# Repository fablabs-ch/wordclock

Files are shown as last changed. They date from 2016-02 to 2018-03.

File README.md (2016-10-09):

# WordClock

This is our adaptation of the [Javelin's Word Clock][javelin-word-clock].

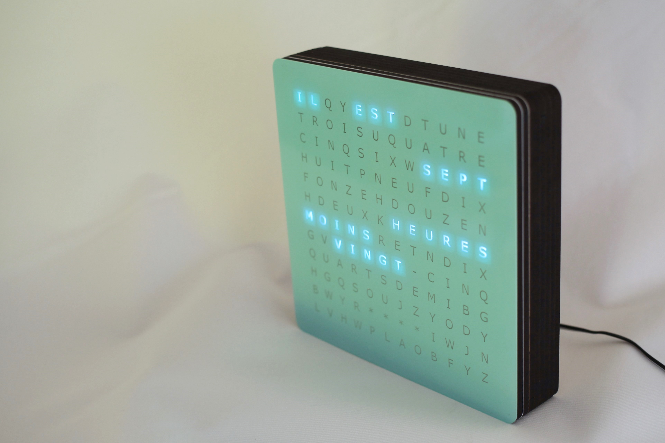
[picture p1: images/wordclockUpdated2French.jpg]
Swiss FabLabs WordClock


## Documentation

You can find all the documentation in the [Wiki][wiki]

* [User manual][user-manual]

## Initial development

The initial development take place on different platforms:

- [Trello][trello-fablabs-ch] for the tasks and progression management.
- [Slack's `#fab-jam_make-athon` channel][slack-fab-jam] for discussions.

## License

This work is licensed under a
[Creative Commons Attribution-NonCommercial-ShareAlike 4.0 International License][by-nc-sa].
Some files may be released under a different license. When this is the case the
license is specified in the file header. This is mainly used for software codes
for which Creative Commons licenses are not well suited.

[][by-nc-sa]

[javelin-word-clock]: http://www.instructables.com/id/Javelins-Word-Clock/
[wiki]: https://github.com/fablabs-ch/wordclock/wiki
[user-manual]: https://github.com/fablabs-ch/wordclock/wiki/User-manual
[trello-fablabs-ch]: https://trello.com/fablabsuisses
[slack-fab-jam]: https://fablabs-ch.slack.com/messages/fab-jam_make-athon/details/
[by-nc-sa]: http://creativecommons.org/licenses/by-nc-sa/4.0/

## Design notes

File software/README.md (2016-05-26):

#Arduino code for the wordclock

#Requirement

The arduino programme require two libraries
 * [TimerOne](https://github.com/PaulStoffregen/TimerOne.git)
 * [DS3231.h](https://github.com/jarzebski/Arduino-DS3231.git)

Clone these librairie in the folder arduino/libraries, restart your arduino IDE and you're good to go. The arduino folder is usually located in _My Documents_ (example : `C:\Users\Gaetan\Documents\Arduino\libraries`)

```sh
cd C:\Users\Gaetan\Documents\Arduino\libraries
git clone https://github.com/PaulStoffregen/TimerOne.git
git clone https://github.com/jarzebski/Arduino-DS3231.git
```

##State diagram
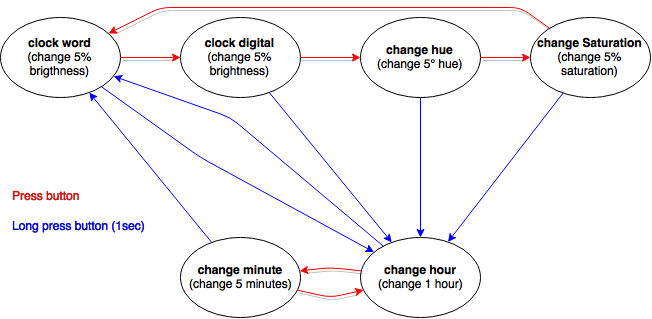
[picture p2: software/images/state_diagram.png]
class diagram State diagram


##Class diagram
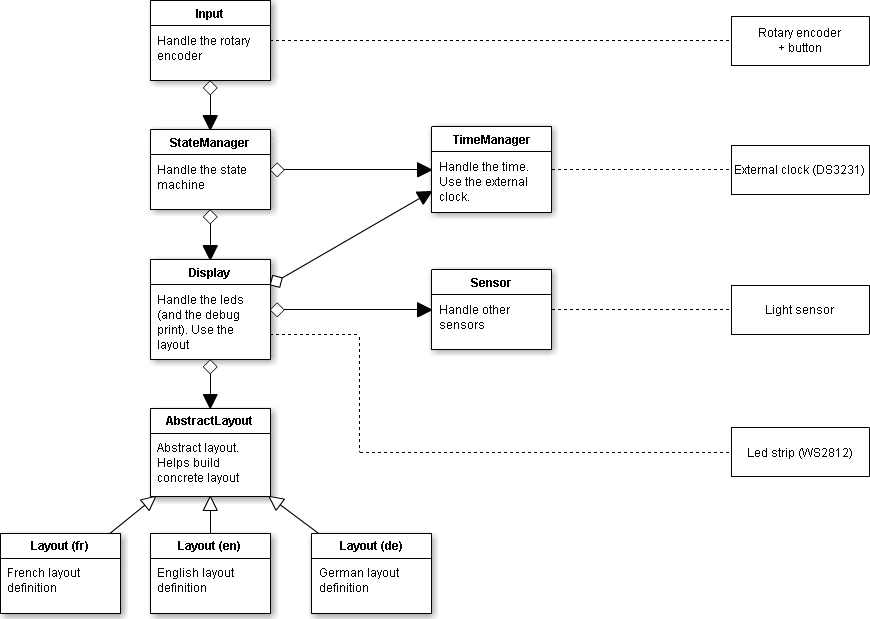
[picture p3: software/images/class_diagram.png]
class diagram Class diagram


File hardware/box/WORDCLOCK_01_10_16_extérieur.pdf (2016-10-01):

découpe
découpe
gravage

Wordclock_Swiss FabLab_extérieur_épaisseur fine

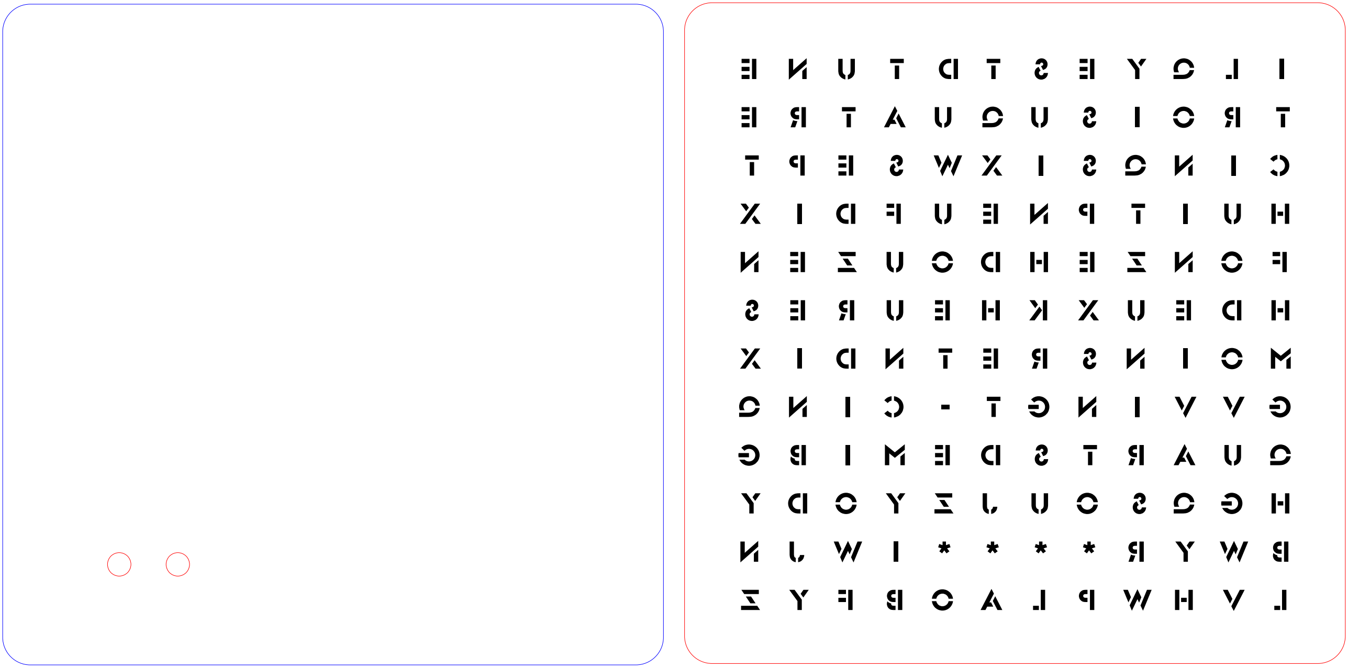
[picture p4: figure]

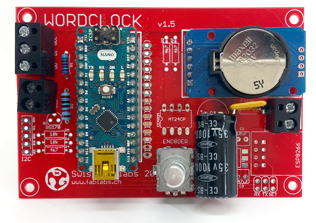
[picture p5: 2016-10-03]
hardware/electronic/pics/default_pcb.jpg

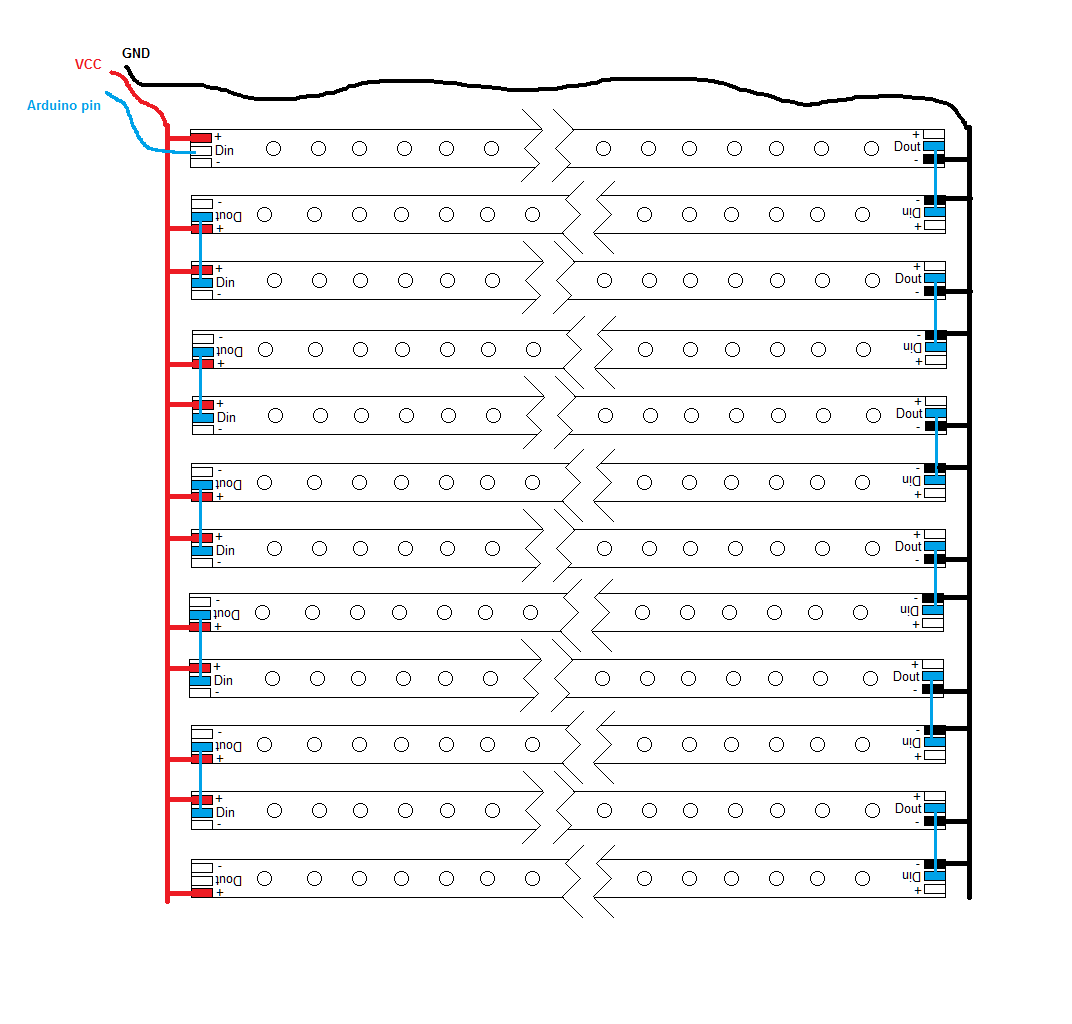
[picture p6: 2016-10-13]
hardware/electronic/pics/led_wordc.bmp

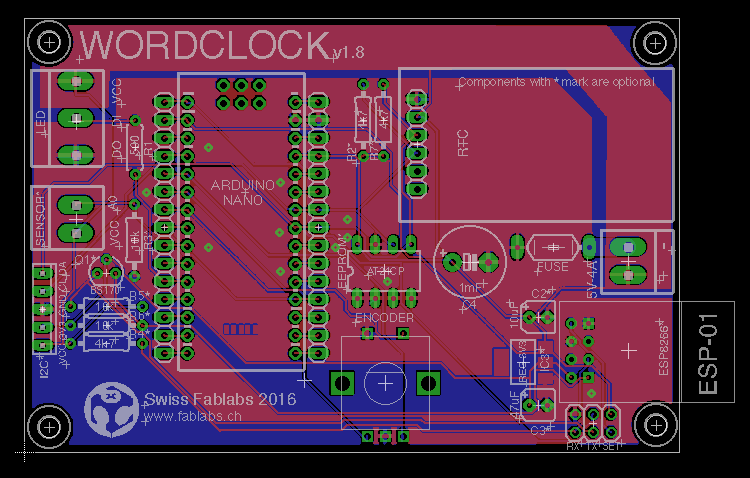
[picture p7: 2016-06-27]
hardware/electronic/pcb_overview.png

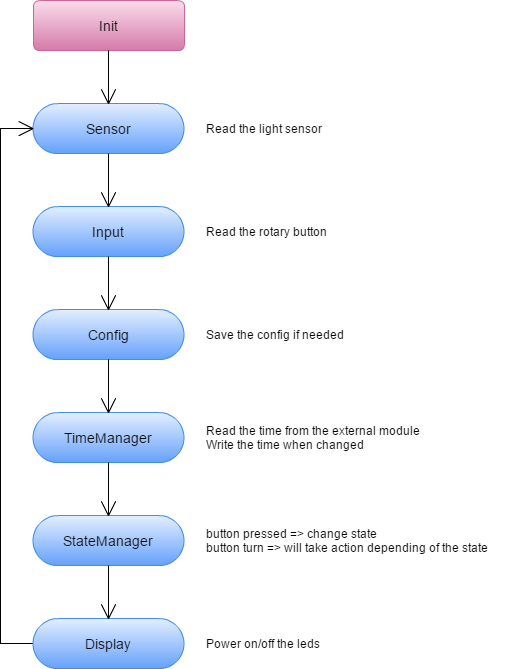
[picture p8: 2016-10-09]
software/images/main_loop.png

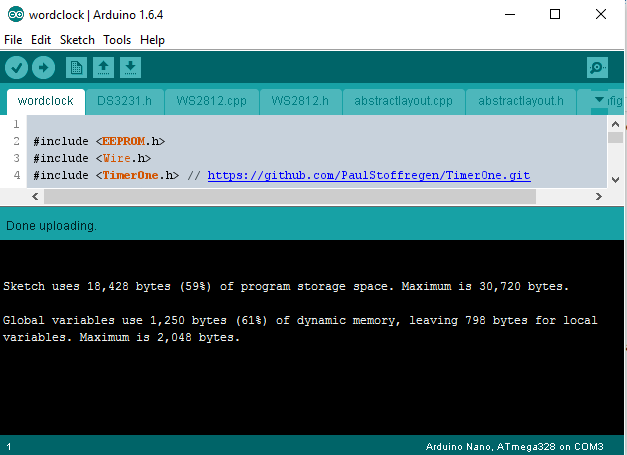
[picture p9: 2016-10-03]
images/wiki/arduino_ide_upload_code.png

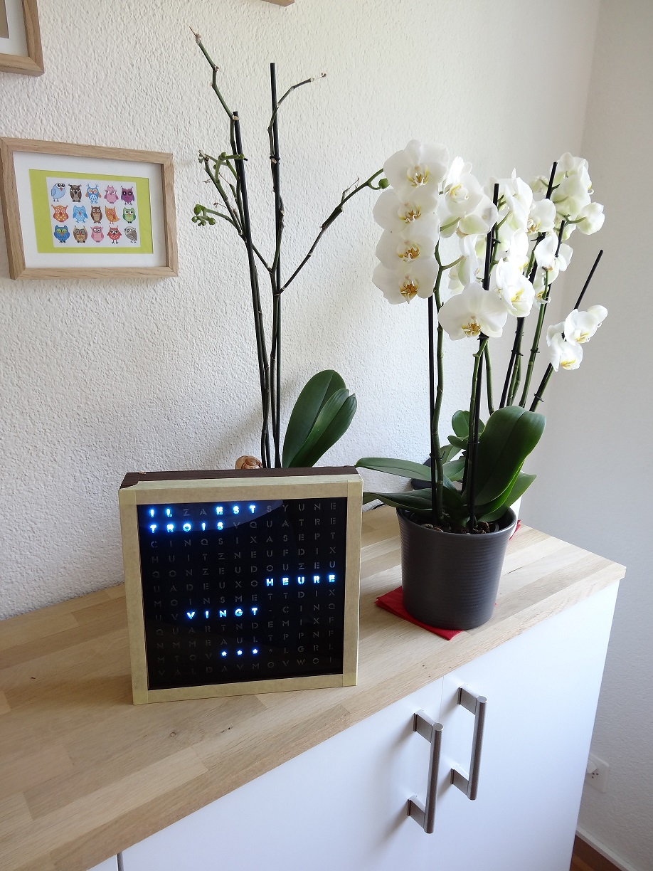
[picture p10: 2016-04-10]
images/wordclock_french.jpg

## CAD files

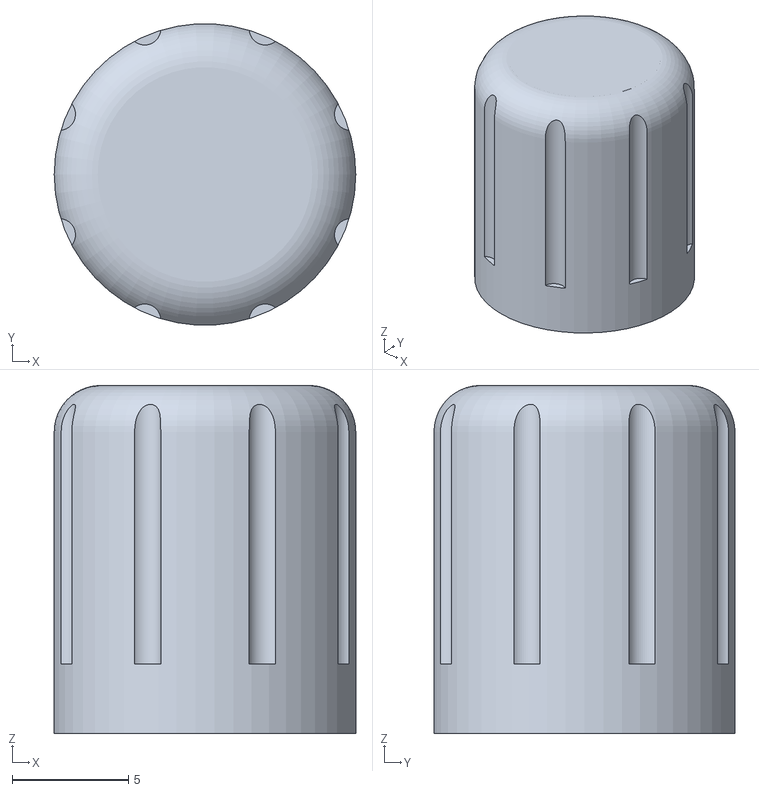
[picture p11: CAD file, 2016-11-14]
hardware/knob/knob.stl
13.0 x 13.0 x 15.0

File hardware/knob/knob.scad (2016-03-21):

/* [Global] */
//Diametre du bouton
Knob_Diameter=13; //[10:30]
//Hauteur du bouton
Knob_Height=15;//[10:20]
//Longueur de l'axe
Axis_Length=10;//[5:15]
//Arrondis
Rounded=2;//[1:3]
//Ajustement
Adjustment=0.5;//[0,0.1,0.2,0.3]
/* [Hidden] */
$fn=50;

difference() {
  union() {
      cylinder(r=Knob_Diameter/2,h=Knob_Height-Rounded);
      translate([0,0,Knob_Height-Rounded]) cylinder(r=Knob_Diameter/2-Rounded,h=Rounded);
      translate([0,0,Knob_Height-Rounded]) rotate_extrude(convexity = 10) translate([Knob_Diameter/2-Rounded,0,0])  circle(r=Rounded);
  }
  
  //translate([0,0,Knob_Height]) rotate([-90,0,0]) cylinder(r=0.5,h=Knob_Diameter/2);
  //translate([0,0,Knob_Height]) sphere(r=0.5);
  
  for (i=[22.5:45:360]) translate([(Knob_Diameter+0.6)*sin(i)/2,(Knob_Diameter+0.6)*cos(i)/2,3]) cylinder(r=0.7,h=Knob_Height);
  difference() {
      translate([0,0,2]) cylinder(r=3.1+Adjustment,h=Axis_Length-2);
      translate([-5,-6.6-Adjustment,2]) cube([10,5,Axis_Length-2]);
  }
  difference() {
      cylinder(r=3+Adjustment,h=2);
      translate([-5,-6.5-Adjustment,0]) cube([10,5,Axis_Length-2]);
  }
}

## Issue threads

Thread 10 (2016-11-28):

Fix main PCB label

gaetancollaud, 2016-11-28:
* DO => GND
* add RTC

ccachin, 2017-05-05:
Done in version 1.9

Closed 2017-05-05.

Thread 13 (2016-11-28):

Add holes on leds plate

ccachin, 2016-11-28:
Actually holes are only present on right and left side.
Adding holes in the middle can avoid using tape to fix led strip

Closed 2016-11-28.

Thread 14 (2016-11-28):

Create a basic pcb

ccachin, 2016-11-28:
A polyvalent PCB seems to be not so attractive and people are a bit lost when they have to find where to solder the components.
Idea is to have a smaller pcb with the only mandatory components.

Can maybe linked with issue #7 Try to use an ESP8266 as brain

Closed 2016-11-28.

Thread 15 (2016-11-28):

Add holes on leds plate

ccachin, 2016-11-28:
Currently holes are only present on right and left side.
Adding holes in the middle can avoid using tape to fix led strip

ccachin, 2018-03-20:
Solved with alternative frame
wordclock/hardware/box/Alternative Frame & pcb ledtstrip/wordclock_frame_strip_placement.svg

Closed 2018-03-20.

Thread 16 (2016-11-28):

Create a basic PCB

ccachin, 2016-11-28:
A polyvalent PCB seems to be not so attractive and people are a bit lost when they have to find where to solder the components.
Idea is to have a smaller pcb with the only mandatory components.

Can maybe linked with issue #7 Try to use an ESP8266 as brain

gaetancollaud, 2016-12-17:
I tried PlatformIO recently. It's amazing how the ESP8266 is easy with this platform. Of course we have a lot of refactoring to do... :(

ccachin, 2016-12-19:
What kind of refactoring should we do to use PlateformIO?

gaetancollaud, 2016-12-19:
Since I used C++ 90% of the code is compatible. The issue will be the led strip and the i2c communication. We have to use other libraries.

ccachin, 2017-05-05:
Basic pcb created. See wordclock_zero

Closed 2017-05-05.

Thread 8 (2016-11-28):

Create a PCB to hold the rotary button

gaetancollaud, 2016-11-28:

ccachin, 2017-05-05:
Finally decided to reject this issue. Pull-up are worst on rotary encoder module.

Closed 2017-05-05.

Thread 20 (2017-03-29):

Wire RX/TX

ccachin, 2017-03-29:
Replace RX/TX jumpers with wires

ccachin, 2017-05-05:
Done in version 1.9

Closed 2017-05-05.

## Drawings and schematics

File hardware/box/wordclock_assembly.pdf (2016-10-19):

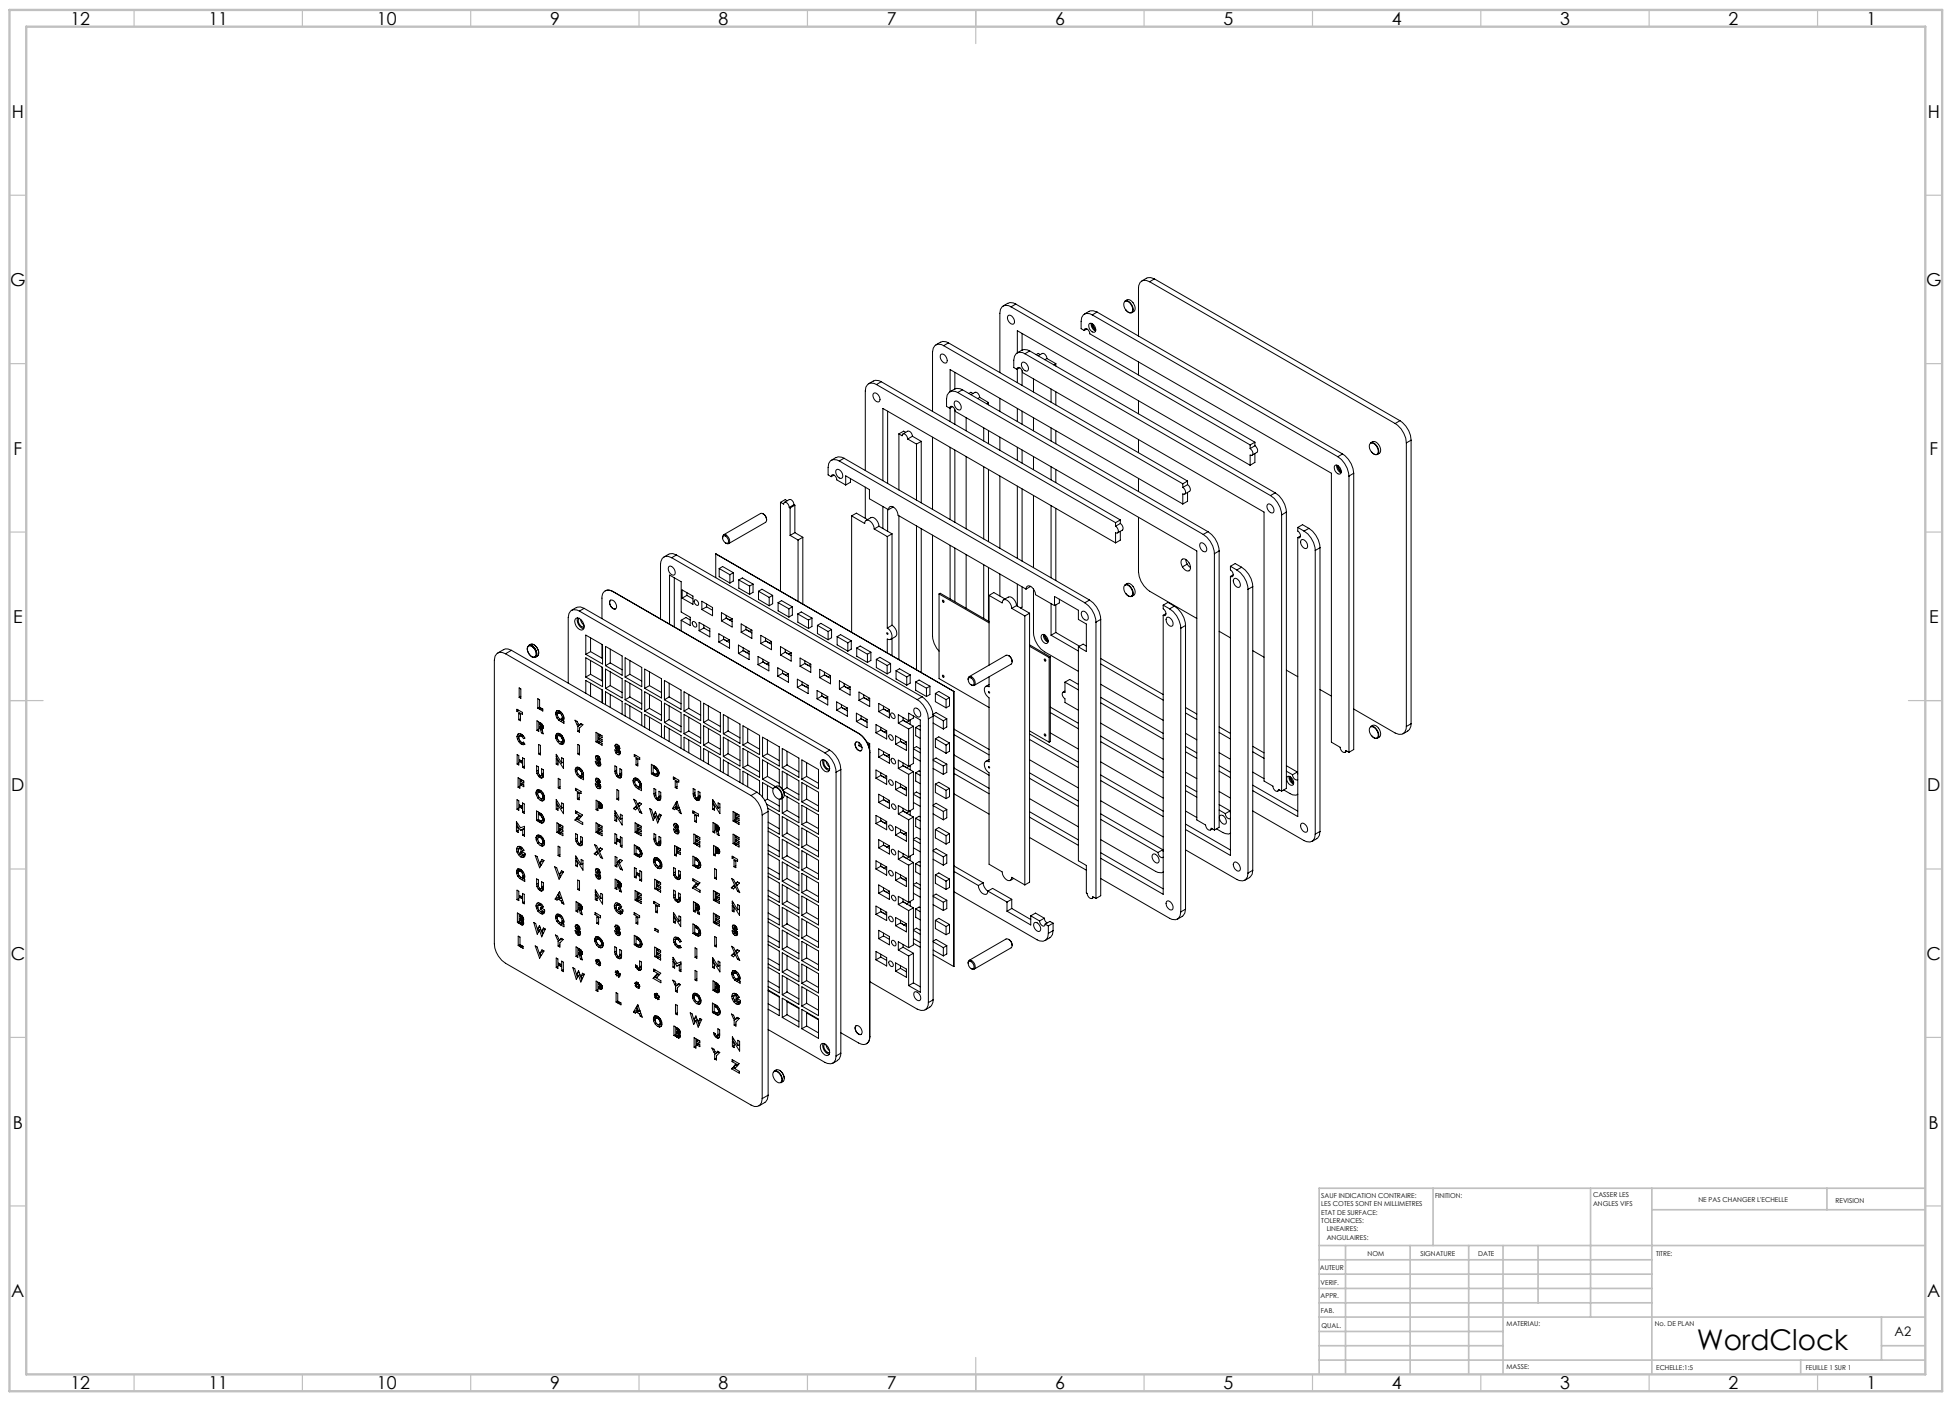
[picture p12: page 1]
ECHELLE:1:5; FEUILLE 1 SUR 1

SAUF INDICATION CONTRAIRE: LES COTES SONT EN MILLIMETRES ETAT DE SURFACE: TOLERANCES: LINEAIRES: ANGULAIRES: | FINITION: | CASSER LES ANGLES VIFS | NE PAS CHANGER L'ECHELLE | REVISION

NOM | SIGNATURE | DATE | | | | TITRE:

AUTEUR
VERIF.
APPR.
FAB.
QUAL. | | | | MATERIAU: | No. DE PLAN WordClock | A2

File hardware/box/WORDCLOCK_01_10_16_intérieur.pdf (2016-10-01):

2x

2x

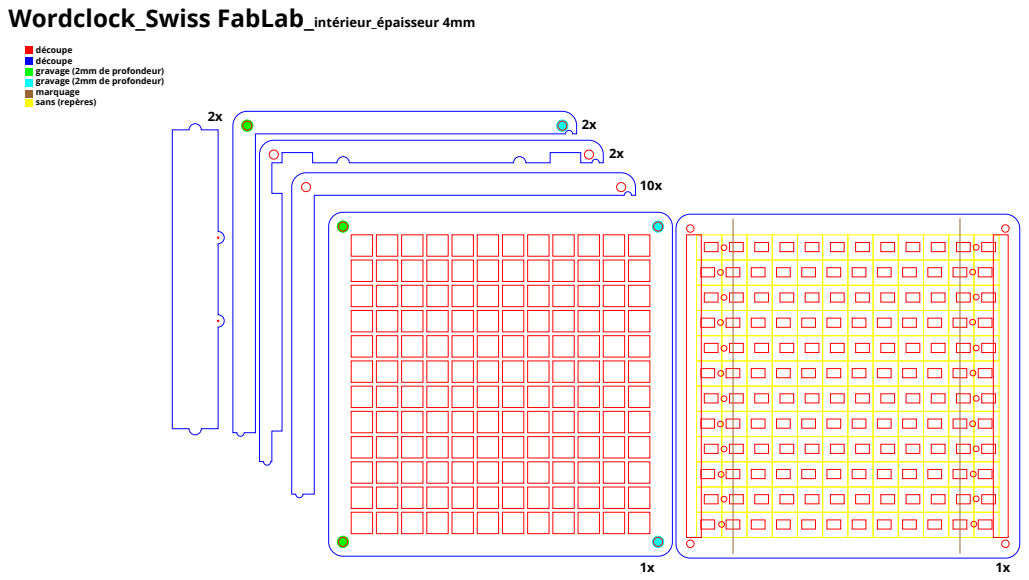
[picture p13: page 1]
Wordclock_Swiss FabLab_intérieur_épaisseur 4mm

découpe
gravage (2mm de profondeur)
marquage
sans (repères)

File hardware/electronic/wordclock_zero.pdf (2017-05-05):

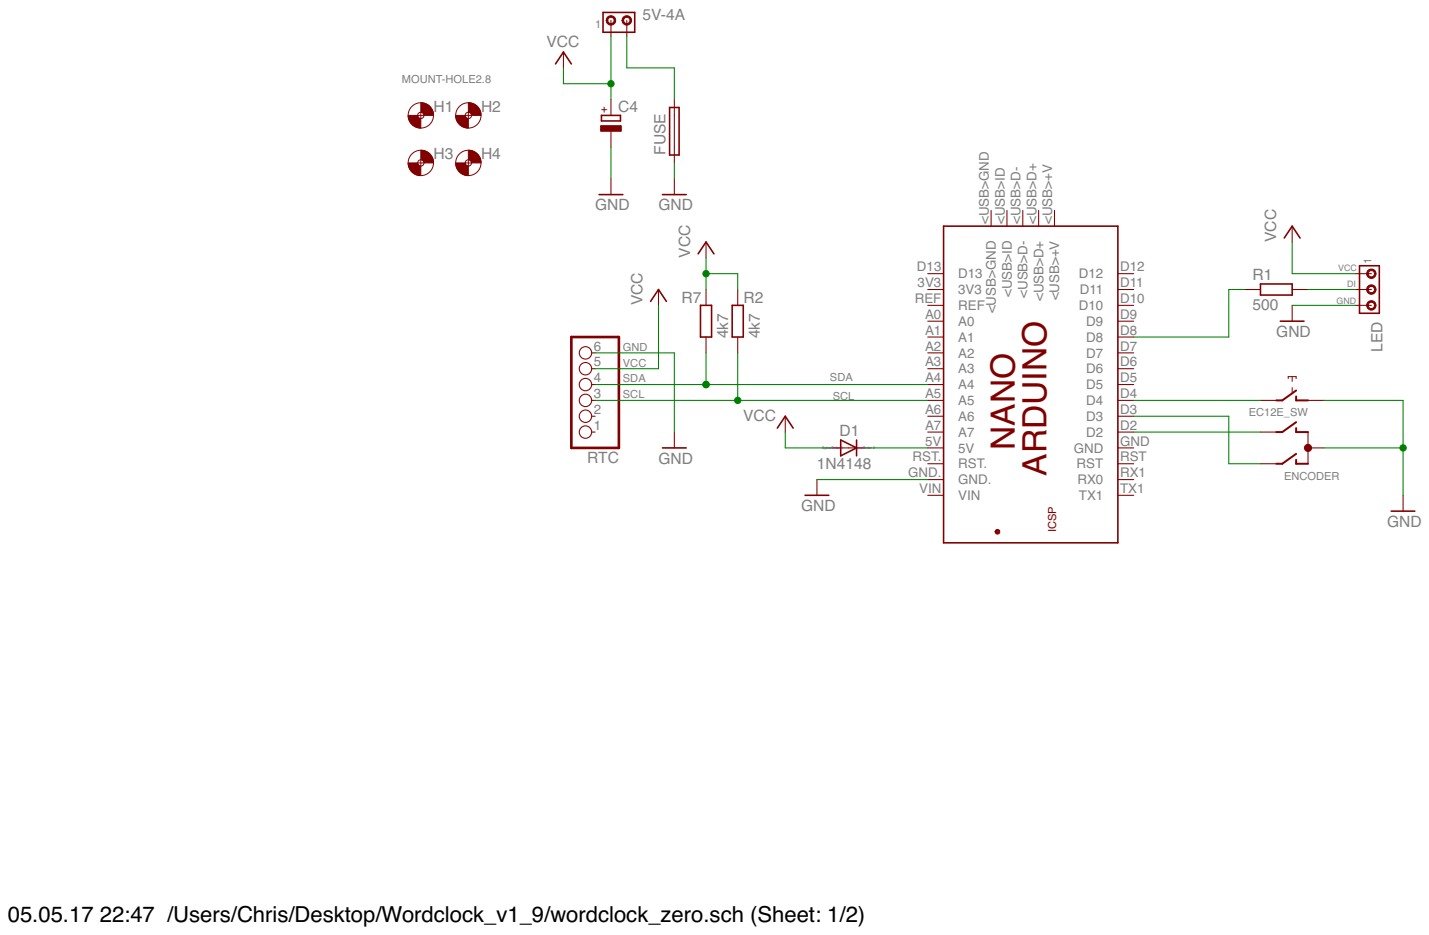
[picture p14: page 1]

05.05.17 22:47 /Users/Chris/Desktop/Wordclock_v1_9/wordclock_zero.sch (Sheet: 1/2)

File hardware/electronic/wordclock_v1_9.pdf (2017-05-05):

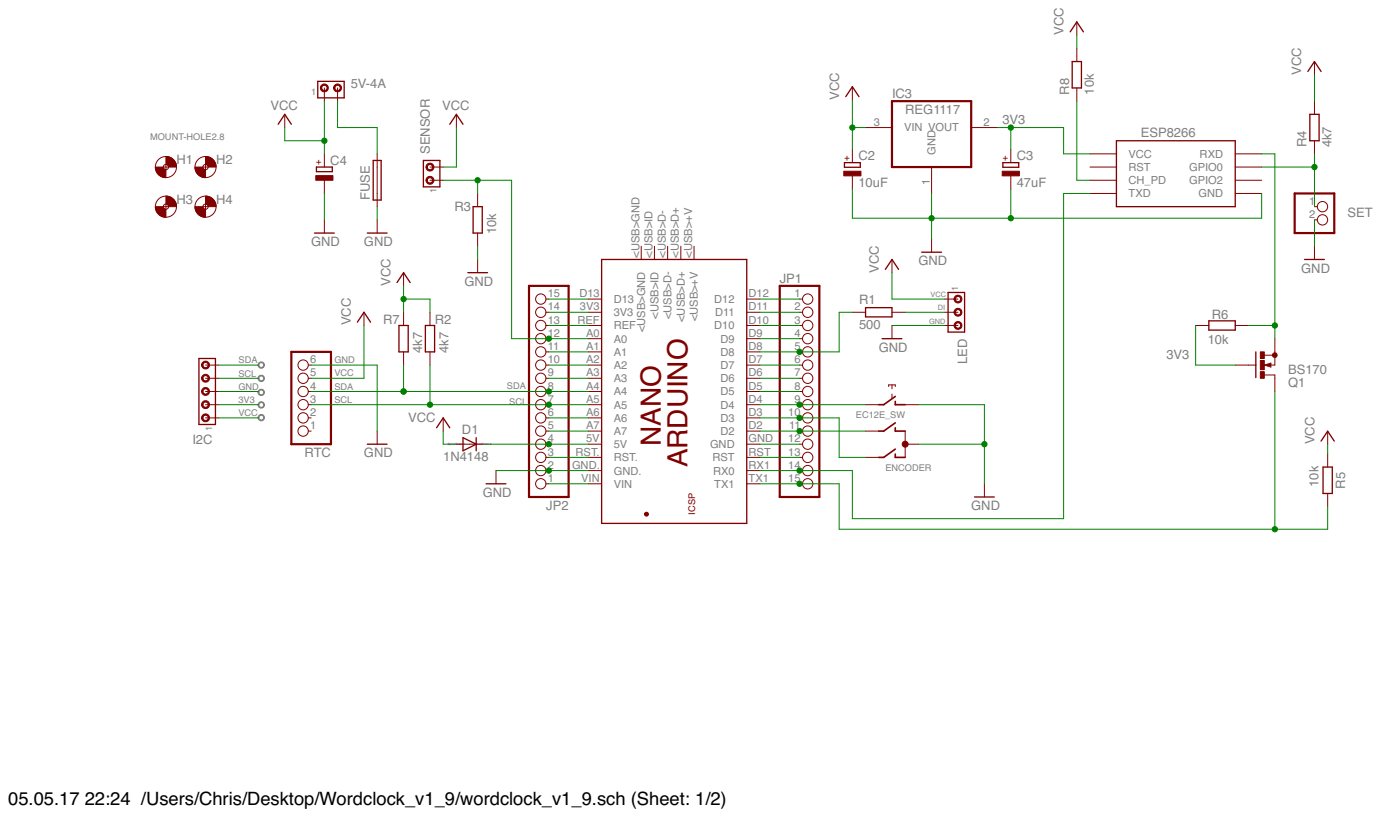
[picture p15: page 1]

05.05.17 22:24 /Users/Chris/Desktop/Wordclock_v1_9/wordclock_v1_9.sch (Sheet: 1/2)

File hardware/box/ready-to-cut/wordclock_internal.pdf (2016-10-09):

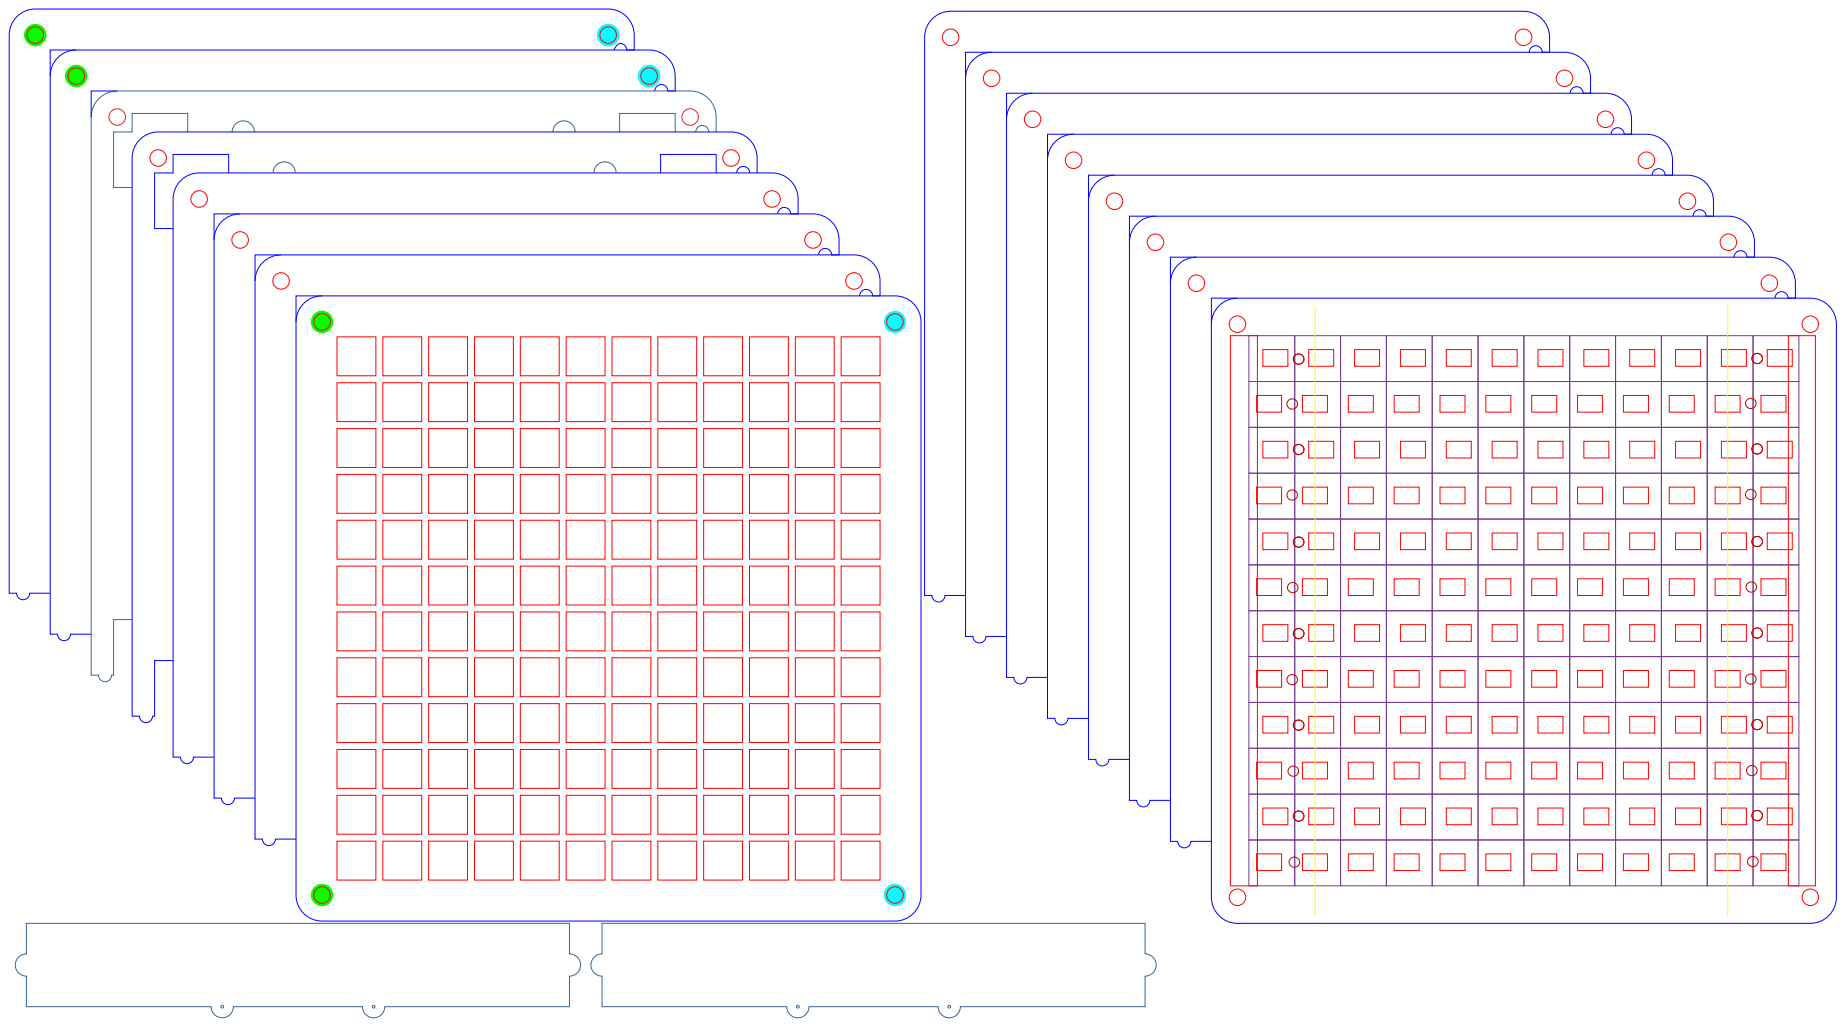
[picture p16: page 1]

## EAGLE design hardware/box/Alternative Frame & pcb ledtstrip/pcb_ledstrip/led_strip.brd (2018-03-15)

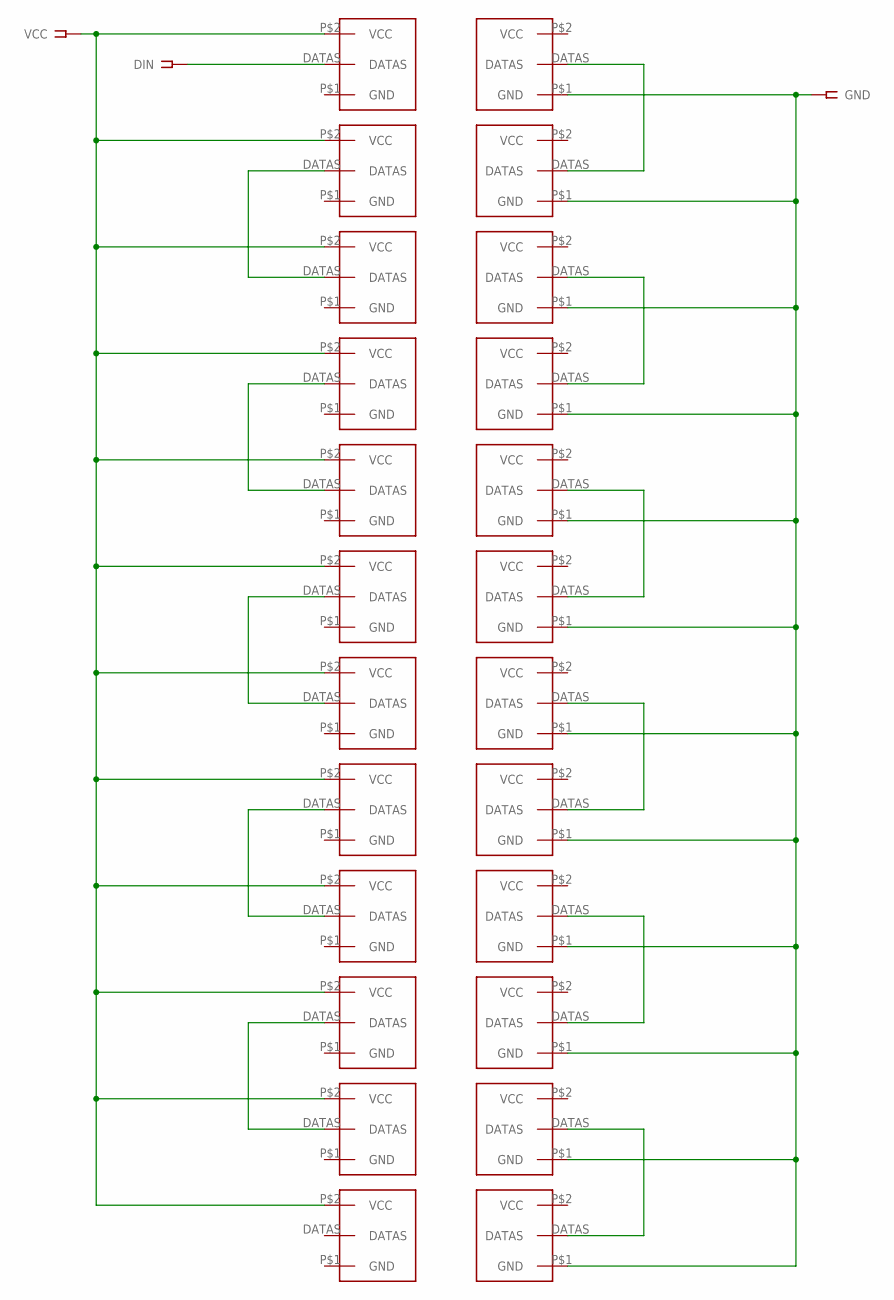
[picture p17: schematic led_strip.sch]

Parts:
1: 1; LED_STRIP
2, 3, 4, 5, 6, 7, 8, 9, 10, 11, 12, 13, 14, 15, 16, 17, 18, 19, 20, 21, 22, 23, 24: LED_STRIP
DIN: DATA; SSW-101-02-S-S
GND: GND; SSW-101-02-S-S
VCC: VCC; SSW-101-02-S-S

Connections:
GND: 1.P$1 (GND), 2.P$1 (GND), 3.P$1 (GND), 4.P$1 (GND), 5.P$1 (GND), 6.P$1 (GND), 7.P$1 (GND), 8.P$1 (GND), 9.P$1 (GND), 10.P$1 (GND), 11.P$1 (GND), 12.P$1 (GND), GND.1
unnamed: 13.DATAS, DIN.1
unnamed: 1.DATAS, 2.DATAS
unnamed: 14.DATAS, 15.DATAS
unnamed: 3.DATAS, 4.DATAS
unnamed: 16.DATAS, 17.DATAS
unnamed: 5.DATAS, 6.DATAS
unnamed: 18.DATAS, 19.DATAS
unnamed: 7.DATAS, 8.DATAS
unnamed: 20.DATAS, 21.DATAS
unnamed: 22.DATAS, 23.DATAS
unnamed: 9.DATAS, 10.DATAS
unnamed: 11.DATAS, 12.DATAS
VCC: 13.P$2 (VCC), 14.P$2 (VCC), 15.P$2 (VCC), 16.P$2 (VCC), 17.P$2 (VCC), 18.P$2 (VCC), 19.P$2 (VCC), 20.P$2 (VCC), 21.P$2 (VCC), 22.P$2 (VCC), 23.P$2 (VCC), 24.P$2 (VCC), VCC.1

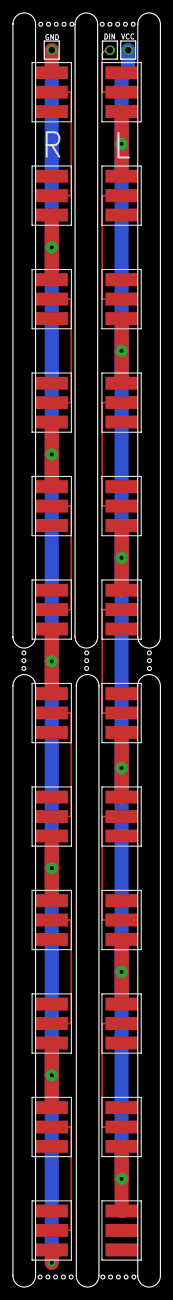
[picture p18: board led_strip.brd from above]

Board: 2 copper layers, 22.8 x 197.0 mm, 27 parts (0 on the bottom side), 14 nets.

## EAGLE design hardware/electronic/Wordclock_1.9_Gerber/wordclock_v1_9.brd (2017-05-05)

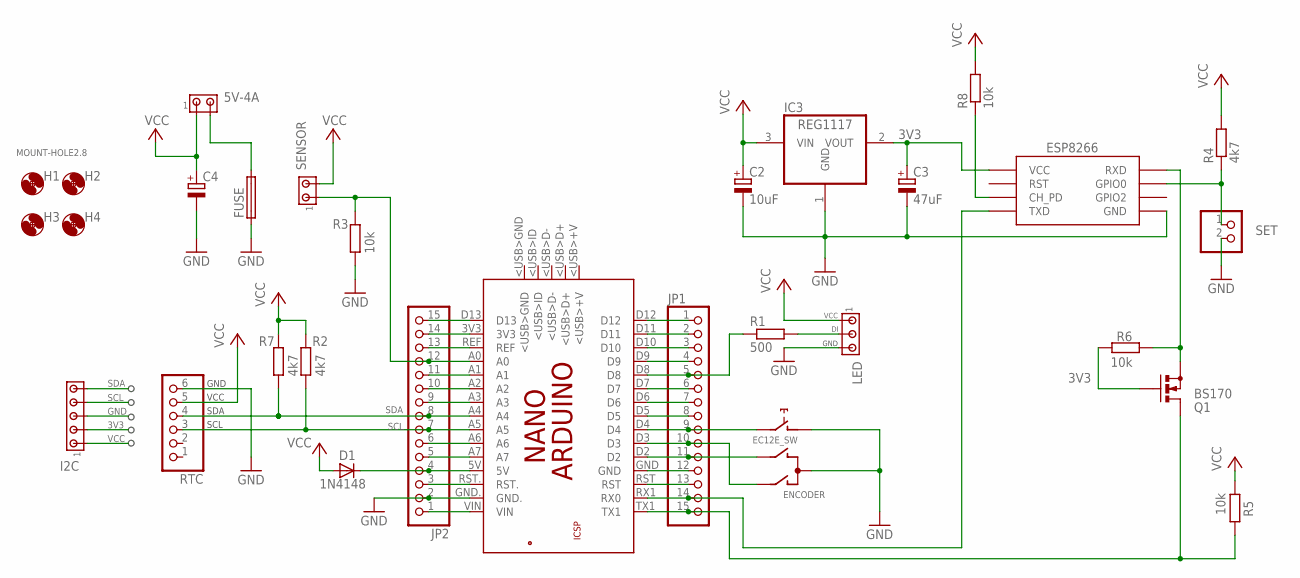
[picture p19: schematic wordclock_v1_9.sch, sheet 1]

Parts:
5V-4A: 5V-4A; 1X2MTA
C2: 10uF; B45181A
C3: 47uF; B45181A
C4: CPOL-EUE5-10.5; E5-10,5
D1: 1N4148; DO35-10
ENCODER: EC12E_SW; ALPS_EC12E_SW
ESP8266: ESP01
FUSE: FUSELITTLEFUSE; LITTLEFUSE
H1, H2, H3, H4: MOUNT-HOLE2.8; 2,8
I2C: MTA05-100; 10X05MTA
IC3: REG1117; SOT223
JP1, JP2: PINHD-1X15; 1X15
LED: MTA03-156; 1X3MTA
PCB2: ARDUINO_NANO
Q1: BS170; SOT54E
R1: 500; 0207/7
R2, R4, R7: 4k7; 0207/10
R3, R5, R6, R8: 10k; 0207/10
RTC: PINHD-1X6; 1X06
SENSOR: MTA02-156; 1X2MTA
SET: PINHD-1X2; 1X02

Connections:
3V3: C3.+, ESP8266.VCC, I2C.2, IC3.2 (VOUT), Q1.G, R6.1
DI: LED.2, R1.2
GND: C2.-, C3.-, C4.-, ENCODER.C, ENCODER.D (1), ESP8266.GND, FUSE.1, I2C.3, IC3.1 (GND), JP2.2, LED.3, PCB2.GND., R3.1, RTC.6, SET.2
unnamed: ESP8266.CH_PD, R8.1
unnamed: JP1.1, PCB2.D12
unnamed: JP1.2, PCB2.D11
unnamed: JP1.5, PCB2.D8, R1.1
unnamed: 5V-4A.2, FUSE.2
unnamed: ENCODER.B, JP1.11, PCB2.D2
unnamed: ENCODER.A, JP1.10, PCB2.D3
unnamed: ENCODER.E (2), JP1.9, PCB2.D4
unnamed: JP1.3, PCB2.D10
unnamed: JP1.15, PCB2.TX1, Q1.D, R5.2
unnamed: D1.C, JP2.4, PCB2.5V
unnamed: JP2.12, PCB2.A0, R3.2, SENSOR.1
unnamed: JP1.4, PCB2.D9
unnamed: JP1.6, PCB2.D7
unnamed: ESP8266.RX (RXD), Q1.S, R6.2
unnamed: JP1.7, PCB2.D6
unnamed: JP1.8, PCB2.D5
unnamed: JP1.12, PCB2.GND
unnamed: JP1.13, PCB2.RST
unnamed: JP2.15, PCB2.D13
unnamed: JP2.14, PCB2.3V3
unnamed: JP2.13, PCB2.REF
unnamed: JP2.11, PCB2.A1
unnamed: JP2.10, PCB2.A2
unnamed: JP2.9, PCB2.A3
unnamed: JP2.6, PCB2.A6
unnamed: JP2.5, PCB2.A7
unnamed: JP2.3, PCB2.RST.
unnamed: JP2.1, PCB2.VIN
RX: ESP8266.TX (TXD), JP1.14, PCB2.RX1 (RX0)
SCL: I2C.4, JP2.7, PCB2.A5, R2.1, RTC.3
SDA: I2C.5, JP2.8, PCB2.A4, R7.1, RTC.4
SET: ESP8266.GPIO0, R4.1, SET.1
VCC: 5V-4A.1, C2.+, C4.+, D1.A, I2C.1, IC3.3 (VIN), LED.1, R2.2, R4.2, R5.1, R7.2, R8.2, RTC.5, SENSOR.2

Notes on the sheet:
SDA
SCL
GND
VCC

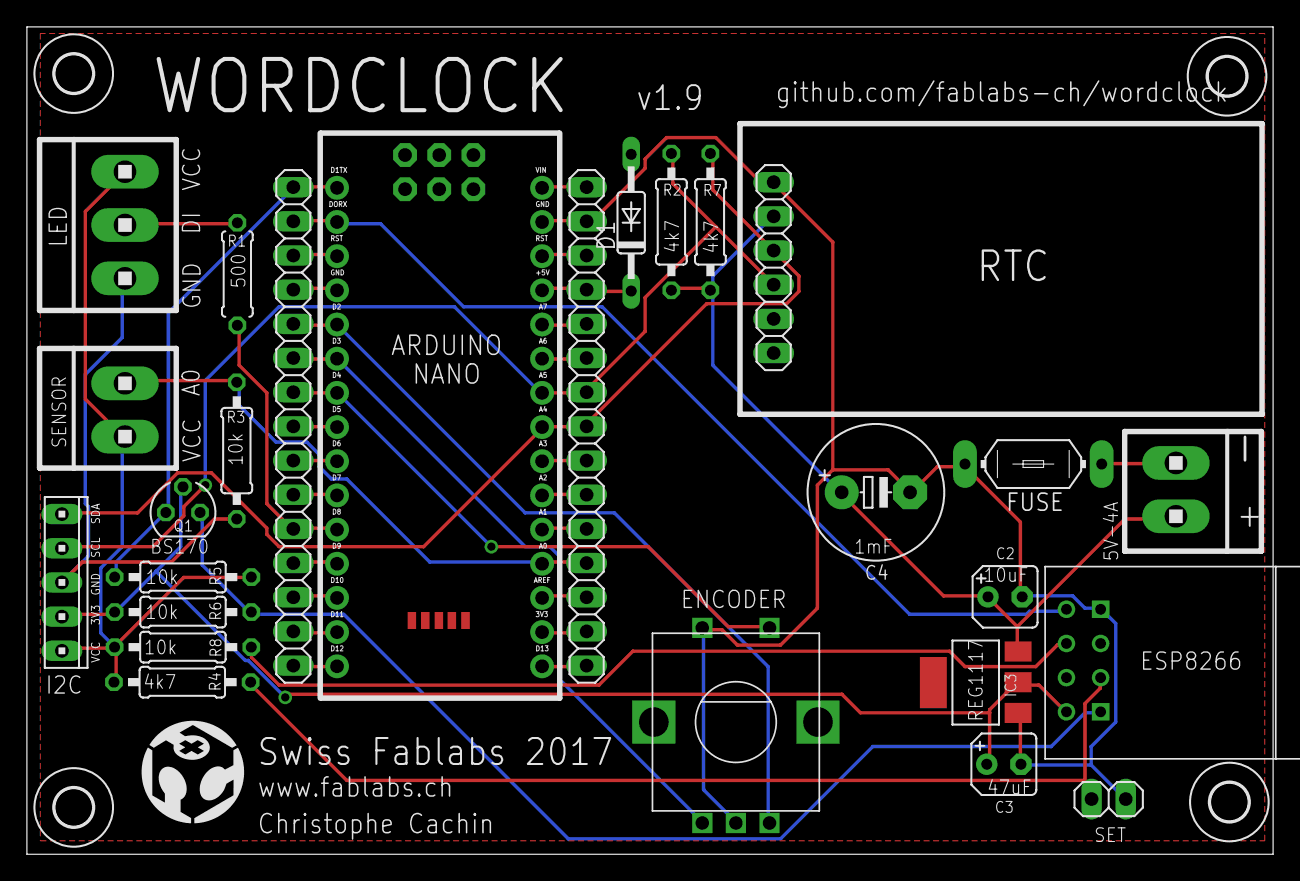
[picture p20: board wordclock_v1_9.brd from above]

Board: 2 copper layers, 92.6 x 61.5 mm, 30 parts (0 on the bottom side), 37 nets.

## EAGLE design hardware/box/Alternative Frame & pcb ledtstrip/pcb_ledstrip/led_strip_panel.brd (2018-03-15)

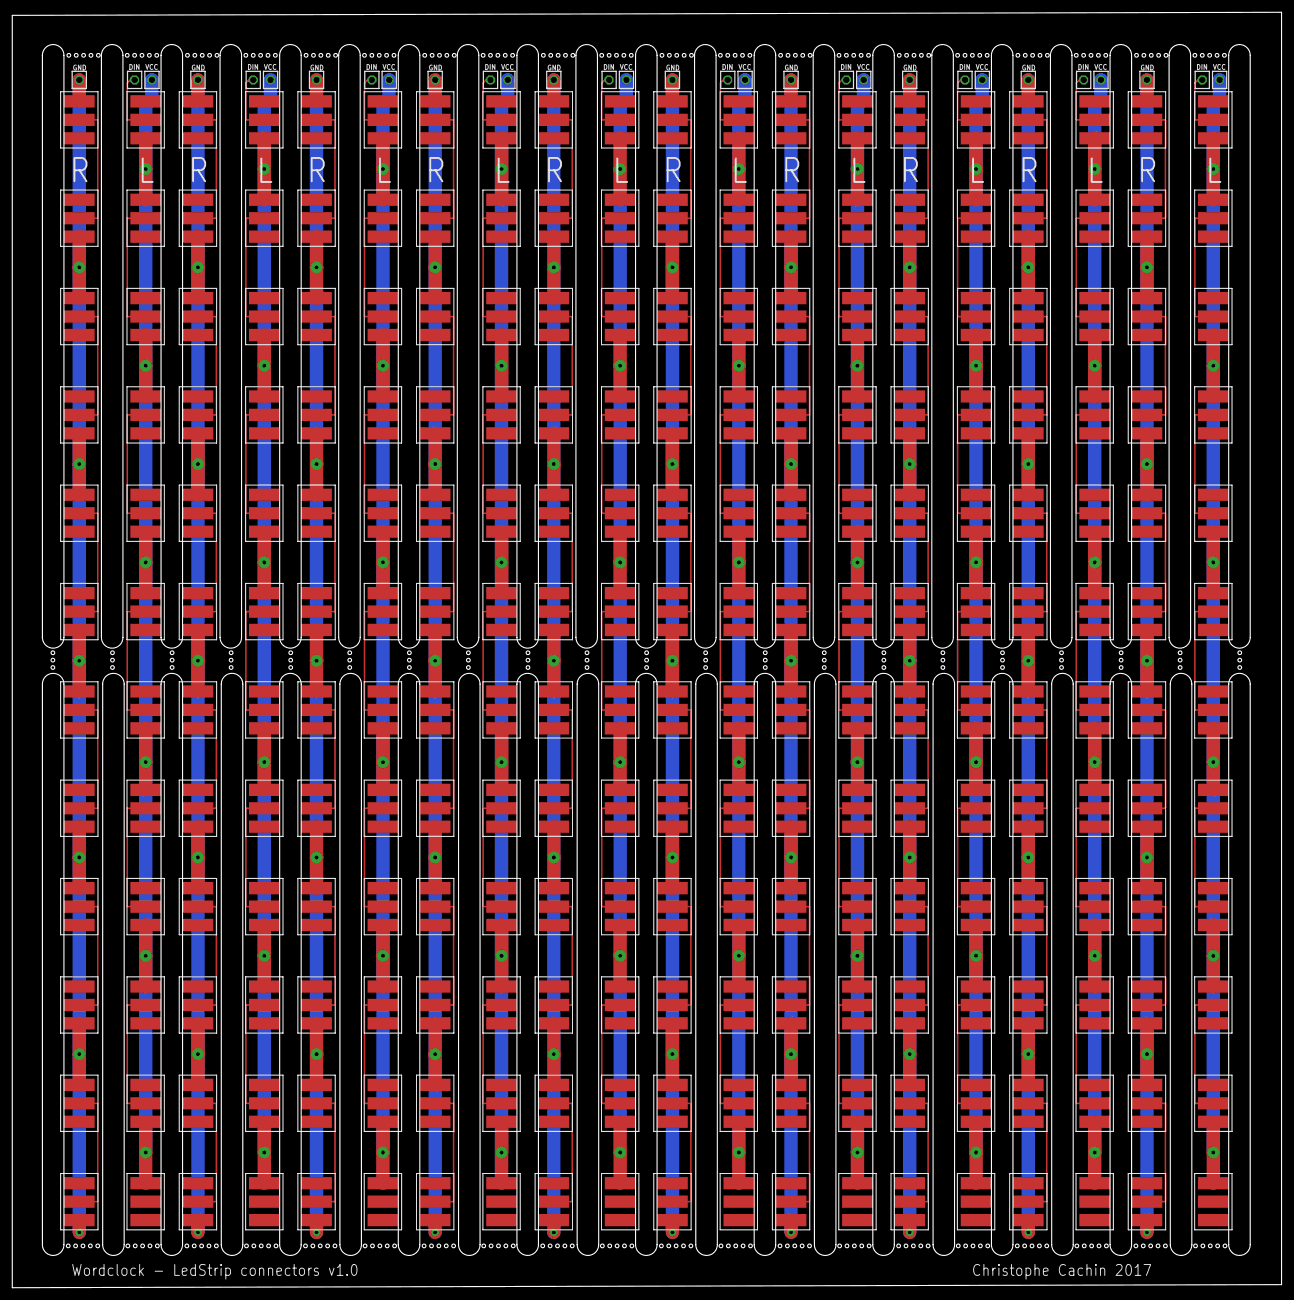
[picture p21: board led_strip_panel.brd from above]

Board: 2 copper layers, 206.5 x 207.5 mm, 270 parts (0 on the bottom side), 140 nets.

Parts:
1, 25, 49, 73, 97, 121, 145, 169, 193, 217: 1; LED_STRIP
2, 3, 4, 5, 6, 7, 8, 9, 10, 11, 12, 13, 14, 15, 16, 17, 18, 19, 20, 21, 22, 23, 24, 26, 27, 28, 29, 30, 31, 32, 33, 34, 35, 36, 37, 38, 39, 40, 41, 42, 43, 44, 45, 46, 47, 48, 50, 51, 52, 53, 54, 55, 56, 57, 58, 59, 60, 61, 62, 63, 64, 65, 66, 67, 68, 69, 70, 71, 72, 74, 75, 76, 77, 78, 79, 80, 81, 82, 83, 84, 85, 86, 87, 88, 89, 90, 91, 92, 93, 94, 95, 96, 98, 99, 100, 101, 102, 103, 104, 105, 106, 107, 108, 109, 110, 111, 112, 113, 114, 115, 116, 117, 118, 119, 120, 122, 123, 124, 125, 126, 127, 128, 129, 130, 131, 132, 133, 134, 135, 136, 137, 138, 139, 140, 141, 142, 143, 144, 146, 147, 148, 149, 150, 151, 152, 153, 154, 155, 156, 157, 158, 159, 160, 161, 162, 163, 164, 165, 166, 167, 168, 170, 171, 172, 173, 174, 175, 176, 177, 178, 179, 180, 181, 182, 183, 184, 185, 186, 187, 188, 189, 190, 191, 192, 194, 195, 196, 197, 198, 199, 200, 201, 202, 203, 204, 205, 206, 207, 208, 209, 210, 211, 212, 213, 214, 215, 216, 218, 219, 220, 221, 222, 223, 224, 225, 226, 227, 228, 229, 230, 231, 232, 233, 234, 235, 236, 237, 238, 239, 240: LED_STRIP
DIN, DIN1, DIN2, DIN3, DIN4, DIN5, DIN6, DIN7, DIN8, DIN9: DATA; SSW-101-02-S-S
GND, GND1, GND2, GND3, GND4, GND5, GND6, GND7, GND8, GND9: GND; SSW-101-02-S-S
VCC, VCC1, VCC2, VCC3, VCC4, VCC5, VCC6, VCC7, VCC8, VCC9: VCC; SSW-101-02-S-S

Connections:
GND: 1.P$1, 2.P$1, 3.P$1, 4.P$1, 5.P$1, 6.P$1, 7.P$1, 8.P$1, 9.P$1, 10.P$1, 11.P$1, 12.P$1, GND.1
GND1: 25.P$1, 26.P$1, 27.P$1, 28.P$1, 36.P$1, 42.P$1, 43.P$1, 44.P$1, 45.P$1, 46.P$1, 47.P$1, 48.P$1, GND1.1
GND2: 49.P$1, 50.P$1, 51.P$1, 52.P$1, 60.P$1, 66.P$1, 67.P$1, 68.P$1, 69.P$1, 70.P$1, 71.P$1, 72.P$1, GND2.1
GND3: 73.P$1, 74.P$1, 75.P$1, 76.P$1, 84.P$1, 90.P$1, 91.P$1, 92.P$1, 93.P$1, 94.P$1, 95.P$1, 96.P$1, GND3.1
GND4: 97.P$1, 98.P$1, 99.P$1, 100.P$1, 108.P$1, 114.P$1, 115.P$1, 116.P$1, 117.P$1, 118.P$1, 119.P$1, 120.P$1, GND4.1
GND5: 121.P$1, 122.P$1, 123.P$1, 124.P$1, 132.P$1, 138.P$1, 139.P$1, 140.P$1, 141.P$1, 142.P$1, 143.P$1, 144.P$1, GND5.1
GND6: 145.P$1, 146.P$1, 147.P$1, 148.P$1, 156.P$1, 162.P$1, 163.P$1, 164.P$1, 165.P$1, 166.P$1, 167.P$1, 168.P$1, GND6.1
GND7: 169.P$1, 170.P$1, 171.P$1, 172.P$1, 180.P$1, 186.P$1, 187.P$1, 188.P$1, 189.P$1, 190.P$1, 191.P$1, 192.P$1, GND7.1
GND8: 193.P$1, 194.P$1, 195.P$1, 196.P$1, 204.P$1, 210.P$1, 211.P$1, 212.P$1, 213.P$1, 214.P$1, 215.P$1, 216.P$1, GND8.1
GND9: 217.P$1, 218.P$1, 219.P$1, 220.P$1, 228.P$1, 234.P$1, 235.P$1, 236.P$1, 237.P$1, 238.P$1, 239.P$1, 240.P$1, GND9.1
unnamed: 13.DATAS, DIN.1
unnamed: 1.DATAS, 2.DATAS
unnamed: 14.DATAS, 15.DATAS
unnamed: 3.DATAS, 4.DATAS
unnamed: 16.DATAS, 17.DATAS
unnamed: 5.DATAS, 6.DATAS
unnamed: 18.DATAS, 19.DATAS
unnamed: 7.DATAS, 8.DATAS
unnamed: 20.DATAS, 21.DATAS
unnamed: 22.DATAS, 23.DATAS
unnamed: 9.DATAS, 10.DATAS
unnamed: 11.DATAS, 12.DATAS
unnamed: 29.DATAS, DIN1.1
unnamed: 25.DATAS, 36.DATAS
unnamed: 30.DATAS, 31.DATAS
unnamed: 42.DATAS, 43.DATAS
unnamed: 32.DATAS, 33.DATAS
unnamed: 44.DATAS, 45.DATAS
unnamed: 34.DATAS, 35.DATAS
unnamed: 46.DATAS, 47.DATAS
unnamed: 37.DATAS, 38.DATAS
unnamed: 39.DATAS, 40.DATAS
unnamed: 26.DATAS, 48.DATAS
unnamed: 27.DATAS, 28.DATAS
unnamed: 53.DATAS, DIN2.1
unnamed: 49.DATAS, 60.DATAS
unnamed: 54.DATAS, 55.DATAS
unnamed: 66.DATAS, 67.DATAS
unnamed: 56.DATAS, 57.DATAS
unnamed: 68.DATAS, 69.DATAS
unnamed: 58.DATAS, 59.DATAS
unnamed: 70.DATAS, 71.DATAS
unnamed: 61.DATAS, 62.DATAS
unnamed: 63.DATAS, 64.DATAS
unnamed: 50.DATAS, 72.DATAS
unnamed: 51.DATAS, 52.DATAS
unnamed: 77.DATAS, DIN3.1
unnamed: 73.DATAS, 84.DATAS
unnamed: 78.DATAS, 79.DATAS
unnamed: 90.DATAS, 91.DATAS
unnamed: 80.DATAS, 81.DATAS
unnamed: 92.DATAS, 93.DATAS
unnamed: 82.DATAS, 83.DATAS
unnamed: 94.DATAS, 95.DATAS
unnamed: 85.DATAS, 86.DATAS
unnamed: 87.DATAS, 88.DATAS
unnamed: 74.DATAS, 96.DATAS
unnamed: 75.DATAS, 76.DATAS
unnamed: 101.DATAS, DIN4.1
unnamed: 97.DATAS, 108.DATAS
unnamed: 102.DATAS, 103.DATAS
unnamed: 114.DATAS, 115.DATAS
unnamed: 104.DATAS, 105.DATAS
unnamed: 116.DATAS, 117.DATAS
unnamed: 106.DATAS, 107.DATAS
unnamed: 118.DATAS, 119.DATAS
unnamed: 109.DATAS, 110.DATAS
unnamed: 111.DATAS, 112.DATAS
unnamed: 98.DATAS, 120.DATAS
unnamed: 99.DATAS, 100.DATAS
unnamed: 125.DATAS, DIN5.1
unnamed: 121.DATAS, 132.DATAS
unnamed: 126.DATAS, 127.DATAS
unnamed: 138.DATAS, 139.DATAS
unnamed: 128.DATAS, 129.DATAS
unnamed: 140.DATAS, 141.DATAS
unnamed: 130.DATAS, 131.DATAS
unnamed: 142.DATAS, 143.DATAS
unnamed: 133.DATAS, 134.DATAS
unnamed: 135.DATAS, 136.DATAS
unnamed: 122.DATAS, 144.DATAS
unnamed: 123.DATAS, 124.DATAS
unnamed: 149.DATAS, DIN6.1
unnamed: 145.DATAS, 156.DATAS
unnamed: 150.DATAS, 151.DATAS
unnamed: 162.DATAS, 163.DATAS
unnamed: 152.DATAS, 153.DATAS
unnamed: 164.DATAS, 165.DATAS
unnamed: 154.DATAS, 155.DATAS
unnamed: 166.DATAS, 167.DATAS
unnamed: 157.DATAS, 158.DATAS
unnamed: 159.DATAS, 160.DATAS
unnamed: 146.DATAS, 168.DATAS
unnamed: 147.DATAS, 148.DATAS
unnamed: 173.DATAS, DIN7.1
unnamed: 169.DATAS, 180.DATAS
unnamed: 174.DATAS, 175.DATAS
unnamed: 186.DATAS, 187.DATAS
unnamed: 176.DATAS, 177.DATAS
unnamed: 188.DATAS, 189.DATAS
unnamed: 178.DATAS, 179.DATAS
unnamed: 190.DATAS, 191.DATAS
unnamed: 181.DATAS, 182.DATAS
unnamed: 183.DATAS, 184.DATAS
unnamed: 170.DATAS, 192.DATAS
unnamed: 171.DATAS, 172.DATAS
unnamed: 197.DATAS, DIN8.1
unnamed: 193.DATAS, 204.DATAS
unnamed: 198.DATAS, 199.DATAS
unnamed: 210.DATAS, 211.DATAS
unnamed: 200.DATAS, 201.DATAS
unnamed: 212.DATAS, 213.DATAS
unnamed: 202.DATAS, 203.DATAS
unnamed: 214.DATAS, 215.DATAS
unnamed: 205.DATAS, 206.DATAS
unnamed: 207.DATAS, 208.DATAS
unnamed: 194.DATAS, 216.DATAS
unnamed: 195.DATAS, 196.DATAS
unnamed: 221.DATAS, DIN9.1
unnamed: 217.DATAS, 228.DATAS
unnamed: 222.DATAS, 223.DATAS
unnamed: 234.DATAS, 235.DATAS
unnamed: 224.DATAS, 225.DATAS
unnamed: 236.DATAS, 237.DATAS
unnamed: 226.DATAS, 227.DATAS
unnamed: 238.DATAS, 239.DATAS
unnamed: 229.DATAS, 230.DATAS
unnamed: 231.DATAS, 232.DATAS
unnamed: 218.DATAS, 240.DATAS
unnamed: 219.DATAS, 220.DATAS
VCC: 13.P$2, 14.P$2, 15.P$2, 16.P$2, 17.P$2, 18.P$2, 19.P$2, 20.P$2, 21.P$2, 22.P$2, 23.P$2, 24.P$2, VCC.1
VCC1: 29.P$2, 30.P$2, 31.P$2, 32.P$2, 33.P$2, 34.P$2, 35.P$2, 37.P$2, 38.P$2, 39.P$2, 40.P$2, 41.P$2, VCC1.1
VCC2: 53.P$2, 54.P$2, 55.P$2, 56.P$2, 57.P$2, 58.P$2, 59.P$2, 61.P$2, 62.P$2, 63.P$2, 64.P$2, 65.P$2, VCC2.1
VCC3: 77.P$2, 78.P$2, 79.P$2, 80.P$2, 81.P$2, 82.P$2, 83.P$2, 85.P$2, 86.P$2, 87.P$2, 88.P$2, 89.P$2, VCC3.1
VCC4: 101.P$2, 102.P$2, 103.P$2, 104.P$2, 105.P$2, 106.P$2, 107.P$2, 109.P$2, 110.P$2, 111.P$2, 112.P$2, 113.P$2, VCC4.1
VCC5: 125.P$2, 126.P$2, 127.P$2, 128.P$2, 129.P$2, 130.P$2, 131.P$2, 133.P$2, 134.P$2, 135.P$2, 136.P$2, 137.P$2, VCC5.1
VCC6: 149.P$2, 150.P$2, 151.P$2, 152.P$2, 153.P$2, 154.P$2, 155.P$2, 157.P$2, 158.P$2, 159.P$2, 160.P$2, 161.P$2, VCC6.1
VCC7: 173.P$2, 174.P$2, 175.P$2, 176.P$2, 177.P$2, 178.P$2, 179.P$2, 181.P$2, 182.P$2, 183.P$2, 184.P$2, 185.P$2, VCC7.1
VCC8: 197.P$2, 198.P$2, 199.P$2, 200.P$2, 201.P$2, 202.P$2, 203.P$2, 205.P$2, 206.P$2, 207.P$2, 208.P$2, 209.P$2, VCC8.1
VCC9: 221.P$2, 222.P$2, 223.P$2, 224.P$2, 225.P$2, 226.P$2, 227.P$2, 229.P$2, 230.P$2, 231.P$2, 232.P$2, 233.P$2, VCC9.1

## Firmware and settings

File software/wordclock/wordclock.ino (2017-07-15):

//libs
#include <EEPROM.h>
#include <Wire.h>
#include "libs/DS3231.h"
#include "libs/DS3231.cpp"
#include "libs/WS2812.h"
#include "libs/light_ws2812.cpp"
#include "libs/WS2812.cpp"

//components
#include "statemanager.h"
#include "timemanager.h"
#include "input.h"
#include "display.h"
#include "sensors.h"

//layouts
#include "layouts/digitallayout.h"
#include "layouts/digitallayout.cpp"
#include "layouts/abstractlayout.h"
#include "layouts/abstractlayout.cpp"
#include "layouts/layout.h"
#include "layouts/layout.fr.cpp"
#include "layouts/layout.en.cpp"
#include "layouts/layout.de.cpp"


WS2812 ws2812(DISPLAY_LEDS);
Config config;
Layout wordLayout;
DigitalLayout digitalLayout;
TimeManager timeManager;
Sensors sensors;
Display display(&wordLayout, &digitalLayout, &config, &timeManager, &ws2812, &sensors);
StateManager stateManager(&timeManager, &display, &config);
Input input(&stateManager);

unsigned long lastLoop = 0;

void setup() {
    Serial.begin(115200);

    //!\ WARNING debug display can introduce bug on input reading (due to latency of the loop)
    //display.debug(&Serial);
    config.debug(&Serial);
    //input.debug(&Serial);
    stateManager.debug(&Serial);
//    timeManager.debug(&Serial);
    sensors.debug(&Serial);

    input.readFromSerial(&Serial);

    sensors.init();
    config.init();
    Serial.println("cfg init");
    timeManager.init();
    Serial.println("init time");
    display.init();
    stateManager.init();
    input.init();
    Serial.println("init done");

    //Matrix tester mode if button is pressed when powered on
    if (input.isButtonPressed()) {
        display.matrixTester();
    }
}

void loop() {
    unsigned long now = millis();
    unsigned long dtMs = 0;
    if (lastLoop < now) {
        //or else overflow, keep one as delta
        dtMs = now - lastLoop;
    }

    sensors.loop(dtMs);
    input.loop(dtMs);
    config.loop(dtMs);
    timeManager.loop(dtMs);
    stateManager.loop(dtMs);
    display.loop(dtMs);

    lastLoop = now;
}

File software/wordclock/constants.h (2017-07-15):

#ifndef _CONSTANTS_H
#define _CONSTANTS_H


//Language
//#define LAYOUT_DE
#define LAYOUT_FR
//#define LAYOUT_EN

//Define if you want to substract the minute when after half an hour
#define MINUTES_REVERSE false

//!\ WARNING if 'false' the clock will be simulated
#define USE_EXTERNAL_CLOCK true

//matrix
#define DISPLAY_ROWS 12
#define DISPLAY_COLUMNS 12
#define DISPLAY_LEDS DISPLAY_ROWS*DISPLAY_COLUMNS

//Inputs
#define PIN_ROTARY_BUTTON 4
#define PIN_ROTARY_A 3
#define PIN_ROTARY_B 2
#define ANTI_REBOUND_MS 50

#define BUTTON_LONG_PRESS_MS 1000

//Sensors
#define SENSOR_LIGHT_PIN A0
#define SENSOR_LIGHT_MIN 100
#define SENSOR_LIGHT_MAX 970

//Max auto light
#define LIGHT_MIN_AUTO 5
#define LIGHT_MAX_AUTO 50

//Outputs
#define PIN_LED_STRIP 8

// Uncomment to add motion sensor support
//#define PIN_MOTION_SENSOR 5
//#define MOTION_TIME_MS 60000


#endif

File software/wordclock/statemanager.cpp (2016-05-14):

#include "statemanager.h"

StateManager::StateManager(TimeManager* timeManager, Display* display, Config* config)
  : timeManager(timeManager), display(display), config(config) {
}

void StateManager::init(){
  this->currentState = CLOCK_WORD;

  this->isButtonPressed = false;
  this->isButtonLongPressed = false;
  this->encoderDelta = 0;
}

void StateManager::loop(unsigned long dtMs){
  //defer the action because the callback from the input has to be has quick has possible

  if(this->isButtonPressed){
    this->isButtonPressed = false;
    this->applyButtonPressed();
  }

  if(this->isButtonLongPressed){
    this->isButtonLongPressed = false;
    this->applyButtonLongPressed();
  }

  int delta = this->encoderDelta;
  //possibility to loose encoder change here
  this->encoderDelta = 0;
  if(delta !=0){
    this->applyEncoderDelta(delta);
  }
}

void StateManager::buttonPressed(){
  this->isButtonPressed = true;
}

void StateManager::buttonLongPressed(){
  this->isButtonLongPressed = true;
}

state_type StateManager::getCurrentState(){
  return this->currentState;
}

void StateManager::encoderIncrease(){
  this->encoderDelta++;
}

void StateManager::encoderDecrease(){
  this->encoderDelta--;
}

void StateManager::applyEncoderDelta(int delta){
  switch(this->currentState){
    case CLOCK_WORD:
    case CLOCK_DIGITAL:
      this->applyEncoderDeltaChangeBrightness(delta);
      break;
    case CHANGE_HUE:
      this->applyEncoderDeltaChangeHue(delta);
      break;
    case CHANGE_SATURATION:
      this->applyEncoderDeltaChangeSaturation(delta);
      break;
		case SET_HOUR:
  	  this->applyEncoderDeltaChangeHour(delta);
      break;
		case SET_MINUTE:
      this->applyEncoderDeltaChangeMinute(delta);
      break;
  }
  this->display->draw();
}

void StateManager::applyEncoderDeltaChangeBrightness(int delta){
  hsv_type hsl = this->config->getColor();
  hsl.v = applyDeltaOnValue(hsl.v, delta*2, 0, 100, false);
  this->config->setColor(hsl);
}

void StateManager::applyEncoderDeltaChangeHue(int delta){
  hsv_type hsl = this->config->getColor();
  hsl.h = applyDeltaOnValue(hsl.h, delta*5, 0, 360, true);
  this->config->setColor(hsl);
}

void StateManager::applyEncoderDeltaChangeSaturation(int delta){
  hsv_type hsl = this->config->getColor();
  hsl.s = applyDeltaOnValue(hsl.s, delta*2, 5, 100, false);
  this->config->setColor(hsl);
}

void StateManager::applyEncoderDeltaChangeHour(int delta){
  this->timeManager->addSeconds(delta*3600);
}

void StateManager::applyEncoderDeltaChangeMinute(int delta){
  this->timeManager->addSeconds(delta*60);
}

void StateManager::applyButtonPressed(){
  switch(this->currentState){
    case CLOCK_WORD:
      this->currentState = CLOCK_DIGITAL;
      break;
    case CLOCK_DIGITAL:
      this->currentState = CHANGE_HUE;
      break;
    case CHANGE_HUE:
      this->currentState = CHANGE_SATURATION;
      break;
    case CHANGE_SATURATION:
      this->currentState = CLOCK_WORD;
      break;
		case SET_HOUR:
      this->currentState = SET_MINUTE;
      break;
		case SET_MINUTE:
      this->currentState = SET_HOUR;
      break;
    default:
      this->currentState = CLOCK_WORD;
  }
  this->debugState();
    this->display->setState(this->currentState);
}

void StateManager::applyButtonLongPressed(){
  switch(this->currentState){
    case CLOCK_WORD:
    case CLOCK_DIGITAL:
    case CHANGE_HUE:
    case CHANGE_SATURATION:
      this->timeManager->enterEditionMode();
      this->currentState = SET_MINUTE;
      break;
    default:
      this->timeManager->exitEditionMode();
      this->currentState = CLOCK_WORD;
  }
  this->debugState();
    this->display->setState(this->currentState);
}

void StateManager::debugState(){
  this->debug("State : ");
  switch(this->currentState){
    case CLOCK_WORD:
      this->debug("CLOCK_WORD");
      break;
    case CLOCK_DIGITAL:
      this->debug("CLOCK_DIGITAL");
      break;
    case CHANGE_HUE:
      this->debug("CHANGE_HUE");
      break;
    case CHANGE_SATURATION:
      this->debug("CHANGE_SATURATION");
      break;
		case SET_HOUR:
      this->debug("SET_HOUR");
      break;
		case SET_MINUTE:
      this->debug("SET_MINUTE");
      break;
  }
  this->debugln();
}


int StateManager::applyDeltaOnValue(int v, int incr, int min, int max, bool loop){
  v += incr;
  if(loop){
    int loopV = max-min;
    while(v<=min){
      v+= loopV;
    }
    while(v>max){
      v-= loopV;
    }
  }else{
    if(v<min){
      v=min;
    }else if(v>max){
      v = max;
    }
  }
  return v;
}

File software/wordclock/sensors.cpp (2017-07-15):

#include "sensors.h"

Sensors::Sensors(){
	this->lightIntensity = 128;
}

void Sensors::init(){
	pinMode(SENSOR_LIGHT_PIN, INPUT);

	#ifdef PIN_MOTION_SENSOR
	pinMode(PIN_MOTION_SENSOR, INPUT);
	#endif
}


void Sensors::loop(unsigned long dtMs){
	this->sensorNextRead += dtMs;

	if (this->sensorNextRead >= SENSOR_DELAY_READ_MS) {
		this->sensorNextRead = 0;

		this->readLightSensor();

		bool found=false;
		for(int i=0; i<SENSOR_LAST_VALUE_BUFFER; i++){
			if(this->lightIntensity==this->lastValues[i]){
				found=true;
				break;
			}
		}
		if(!found){
			//the value was not found so, it means it changes a lot => flag big change
			this->bigChange = true;
			debugln("Big light change");

			//insert the value in the last known values
			this->lastValues[this->lastValuesIndex++] = this->lightIntensity;
			if(this->lastValuesIndex==SENSOR_LAST_VALUE_BUFFER){
				this->lastValuesIndex=0;
			}
		}
	}


	#ifdef PIN_MOTION_SENSOR
	if (digitalRead(PIN_MOTION_SENSOR)){
	    if(!this->motionDetected){
	        debugln("MotionDetected");
	    }
	    this->motionDetected = true;
	    this->motionTimeout = MOTION_TIME_MS;
	}else{
	    if(this->motionDetected){
	        this->motionTimeout -= dtMs;
            if(this->motionTimeout<=0){
                this->motionDetected = false;
	            debugln("MotionTimeout");
            }
	    }
	}
	#endif
}

void Sensors::readLightSensor(){
    int sensorValue = analogRead(SENSOR_LIGHT_PIN);

//	debug("Sensor raw: ");
//	debug(sensorValue);
//	debug("\t");

    sensorValue = constrain(sensorValue, SENSOR_LIGHT_MIN, SENSOR_LIGHT_MAX);
	this->lightIntensity = map(sensorValue, SENSOR_LIGHT_MIN, SENSOR_LIGHT_MAX, 0, 255);

//	debug("light: ");
//	debug(this->lightIntensity);
//	debugln();
}

uint8_t Sensors::getLightIntensity(){
    return this->lightIntensity;
}

bool Sensors::bigChangeOccurs(){
	bool r = this->bigChange;
	this->bigChange = false;
	return r;
}

bool Sensors::isMotionDetected(){
    return this->motionDetected;
}

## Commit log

2016-01-23 Add total number of LEDs in layout
2016-01-23 Add informations about holes in the layout
2016-01-23 Distribute holes and add explanation about it
2016-01-23 Moved `doc/layout` to `layouts/`
    [en.csv]
2016-01-24 Formating of code samples in layouts README
2016-01-29 start of the arduino code
2016-01-30 rotary encoder implementation
2016-02-07 arduino readme
2016-02-21 defered input + layout fix
    [input.cpp, layout.cpp]
2016-03-06 small fixes + schema
    [wordclock.fzz]
2016-03-13 know for rotary encoder
    [knob.scad, knob.stl]
2016-03-13 fix knob hole size
    [knob.scad, knob.stl]
2016-03-21 Correct typo in knob.scad
    [knob.scad]
2016-04-02 Update EN layout in Arduino code
2016-04-02 Update FR layout in Arduino code
2016-04-02 matrix tester
    [knob.scad, knob.stl]
2016-04-02 optimize and fix display bug
    [layout.cpp]
2016-04-03 Update Arduino code to support "heures" in plural
2016-04-05 The bluePrints of the different pieces of the box that fit on two boards. The files contain the entire pieces. NOTE that to fit on two boards some pieces have common sides. These sides should be remo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
2016-04-08 Correct "arduino" -> "Arduino" for linux
2016-04-10 reorganize folders
    [wordclock.fzz]
2016-04-10 Schematics
    1er commit des schémas.
    Pas définitif, manque des pull-up sur l’ESP8266 et le mode
    « programmation ».
    [wordclock.brd, wordclock.sch]
2016-04-13 Update schematics
    [wordclock.brd, wordclock.sch]
2016-04-13 PCB + Latest schematic
    [wordclock.brd, wordclock.sch]
2016-04-14 Add jumper to programm ESP
    RX/TX/SET easier to put one pin header instead of three.
    [wordclock.brd, wordclock.sch]
2016-04-15 Latest changes
    Placement and size changes:
    - RTC
    - Capacitor
    ———
    - Extend Arduino pins
    - Add and review labels
    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
    [wordclock.brd, wordclock.sch]
2016-04-16 Update
    Labels layer positions
    [wordclock.brd]
2016-05-02 alternative case and led splitter are designed to reduce the fabrication time
2016-05-14 light sensor
2016-06-27 V1.8
    - Redis connecteur 3poles
    - Correction overlap Sensor
    - Redimensionnement Sérigraphie
    - Mise en évidence des composants optionnel
    - Ajout d’un plan de masse
    [wordclock.brd, wordclock.sch, wordclock_v1_8.brd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]
2016-06-27 Plans de masse
    - Correction des plans de masse
    [wordclock_v1_85.brd]
2016-07-04 lien github
    Ajout du lien github sur le pcb
    [wordclock_v1_85.brd]
2016-08-11 Photos
    PC avec les composants et les différentes parties du pub
2016-10-01 light sensor event
2016-10-01 fix hours in french
    [layout.cpp]
2016-10-01 FIxed Case sensitive file path
2016-10-03 default pcb
2016-10-03 default pcbs without photo res
2016-10-06 ready to cut files
2016-10-13 led wiring
2016-10-16 ready to cut for 594x420mm plate
2016-10-23 Add buttons to load pre-existing languages
2016-11-03 Handle the case where font file are not UTF-8 encoded on windows
2016-11-12 Photo sensor tester
2016-11-13 update knob size
    [knob.scad, knob.stl]
2016-11-14 adjust knob
    [knob.scad, knob.stl]
2016-11-14 rename button
2017-03-18 update de layout comment
2017-05-05 Fix
    Fix:
    - ESP CH_PD pin pull up #21
    - Wire RX/TX #20
    - Fix main PCB label #10
    [wordclock.fzz, wordclock_v1_85.brd, wordclock_v1_9.brd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]
2017-05-05 Basic PCB
    Created basic pcbs without ESP, I2C, EEPROM, SENSOR just essential
    things to make it work basically.
    -> Create a basic PCB #16
    [wordclock_zero.sch]
2017-07-15 disable motion sensor by default
2017-10-04 Add gerber file
    Add gerber files for production
    [wordclock_v1_9.brd, wordclock_v1_9.sch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]
2018-03-15 New frame and pcb for ledstrip
    Save 2 hours with ledstrip soldering
    [led_strip.brd, led_strip.sch, led_strip_panel.brd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]
